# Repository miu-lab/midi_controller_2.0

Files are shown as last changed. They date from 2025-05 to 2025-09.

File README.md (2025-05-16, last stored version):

# MIDI Controller

MIDI Controller est un projet de contrôleur MIDI pour la plateforme Teensy, utilisant PlatformIO pour la gestion du projet et la compilation. Il offre une architecture modulaire et extensible pour le développement d'applications de contrôle MIDI.

## Vue d'ensemble

Ce projet implémente un contrôleur MIDI complet avec:
- Support pour encodeurs rotatifs, boutons et autres contrôles
- Affichage OLED pour l'interface utilisateur
- Communication MIDI via USB
- Gestion de profils et configurations personnalisables

## Architecture

Le projet est organisé selon une architecture hexagonale (aussi appelée architecture en oignon) avec injection de dépendances:

### Couches Principales

- **Core** : Contient la logique métier principale, indépendante de l'implémentation
  - **Domain** : Définitions des entités et interfaces principales
  - **Use Cases** : Implémentation des cas d'utilisation
  - **Ports** : Interfaces pour les adaptateurs
  - **Interfaces** : Contrats abstraits pour les sous-systèmes

- **Adapters** : Implémentations concrètes des interfaces
  - **Primary** : Adaptateurs d'entrée (UI, contrôles)
  - **Secondary** : Adaptateurs de sortie (MIDI, stockage)

- **App** : Point d'entrée de l'application et orchestration
  - **Subsystems** : Sous-systèmes modulaires encapsulant des fonctionnalités complètes
  - **DI** : Système d'injection de dépendances moderne

### Sous-systèmes

L'application est divisée en sous-systèmes indépendants, chacun implémentant une interface abstraite:

- **ConfigurationSubsystem** (`IConfiguration`): Gestion des paramètres et préférences
- **InputSubsystem** (`IInputSystem`): Traitement des entrées utilisateur
- **MidiSubsystem** (`IMidiSystem`): Communication MIDI et mapping
- **UISubsystem** (`IUISystem`): Interface utilisateur et affichage

## Fonctionnalités Principales

- **Mapping MIDI flexible**: Assignez facilement des contrôles à différents messages MIDI
- **Interface utilisateur intuitive**: Navigation par menus sur écran OLED
- **Profils multiples**: Sauvegardez et chargez différentes configurations
- **Mode d'apprentissage**: Apprenez facilement de nouveaux mappings MIDI
- **Modularité**: Ajoutez de nouvelles fonctionnalités sans modifier le code existant

## Compilation et Déploiement

### Prérequis
- PlatformIO
- Teensy Loader
- Librairies Arduino requises (voir platformio.ini)

### Compilation
```bash
pio run
```

### Upload vers le Teensy
```bash
pio run -t upload
```

### Moniteur Série
```bash
pio device monitor
```

## Tests

Le projet comprend une infrastructure de tests unitaires et d'intégration basée sur Unity:

```bash
pio test
```

Les tests couvrent les composants individuels ainsi que l'intégration des sous-systèmes.

## Contribution

Les contributions sont les bienvenues! Veuillez consulter [CONTRIBUTING.md](CONTRIBUTING.md) pour les lignes directrices sur la façon de contribuer au projet.

## Licence

Ce projet est sous licence MIT. Voir le fichier LICENSE pour plus de détails.

## Contact

Pour toute question ou suggestion, veuillez ouvrir une issue sur le dépôt GitHub du projet.

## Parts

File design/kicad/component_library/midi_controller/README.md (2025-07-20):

# MIDI Controller - Bibliothèque de Composants Unifiée

Cette bibliothèque contient tous les composants nécessaires pour le projet de contrôleur MIDI, organisés de manière cohérente et professionnelle.

## Structure de la Bibliothèque

```
midi_controller/
├── midi_controller.kicad_sym     # Symboles schématiques unifiés
├── midi_controller.pretty/       # Footprints PCB
├── 3d_models/                   # Modèles 3D
├── datasheets/                  # Documentation technique
└── README.md                    # Ce fichier
```

## Composants Disponibles

### 🎛️ Microcontrôleurs
- **MIDI_Teensy4.1** - Teensy 4.1 (ARM Cortex-M7 600MHz)
  - Footprint: `Teensy41.kicad_mod`
  - Modèle 3D: `Teensy_4.1_Assembly.STEP`
  - Datasheet: https://www.pjrc.com/store/teensy41.html

### 🖥️ Affichages
- **MIDI_Display_MSP2807** - Écran TFT 2.8" ILI9341 320x240 avec touch
  - Footprint: `MSP2807_ILI9341_Display`
  - Interface: SPI (display) + SPI (touch)
  - Alimentation: 3.3V/5V
  - Résolution: 320×240 pixels
  - Contrôleur: ILI9341
  - Touch controller intégré
  - Utilisé avec LVGL 9.3.0

### 🔄 Encodeurs
- **MIDI_Encoder_PEC11R** - Encodeur mécanique Bourns PEC11R
  - Footprint: `PEC11R4220FS0024.kicad_mod`
  - Modèle 3D: `PEC11R-4020F-S0024.stp`
  - Résolution: 24 impulsions/tour
  - Avec bouton poussoir intégré

- **MIDI_Encoder_E38S6G5_Optical** - Encodeur optique haute précision
  - Footprint: `E38S6G5_Optical_Encoder`
  - Modèle: E38S6G5-600B-G24N
  - Résolution: 600 pulses/révolution
  - Diamètre: Ø38mm
  - Sortie: Open Collector NPN (phases A, B)
  - Alimentation: 5-24V
  - Montage: 3 vis M4 sur cercle Ø30mm
  - Type: Optique incrémental haute précision

### 🔘 Boutons
- **MIDI_Button_Tactile** - Bouton tactile momentané
  - Footprint: `Button_Tactile_6x6mm` (à créer)
  - Type: Momentané NO (Normalement Ouvert)

## Convention de Nommage

### Symboles
- Préfixe: `MIDI_`
- Format: `MIDI_[Catégorie]_[Modèle]`
- Exemple: `MIDI_Encoder_PEC11R`

### Footprints
- Nom descriptif sans préfixe
- Format: `[Modèle]_[Spécification]`
- Exemple: `PEC11R4220FS0024`

### Modèles 3D
- Nom du modèle + extension
- Formats supportés: `.step`, `.stp`, `.wrl`

## Utilisation dans KiCad

### 1. Intégration Automatique
La bibliothèque est automatiquement intégrée via `sym-lib-table` :
```
(lib (name "midi_controller")(type "KiCad")(uri "${KIPRJMOD}/component_library/midi_controller/midi_controller.kicad_sym")(options "")(descr "Unified MIDI Controller Component Library"))
```

### 2. Accès aux Composants
1. Ouvrir l'éditeur de schématique
2. Placer un symbole (touche 'A')
3. Chercher dans la bibliothèque `midi_controller`
4. Sélectionner le composant désiré

### 3. Footprints
Les footprints sont automatiquement associés aux symboles via la propriété `Footprint` :
- Format: `midi_controller:[NomFootprint]`
- Exemple: `midi_controller:Teensy41`

## Gestion des Versions

### Structure de Version
- **v1.0** : Version initiale avec composants de base
- **v1.x** : Ajouts de composants, corrections mineures
- **v2.x** : Modifications majeures de structure

### Changelog
- **v1.0** (2025-01-20) : Création de la bibliothèque unifiée
  - Migration depuis bibliothèques séparées
  - Standardisation des noms et propriétés
  - Documentation complète

## Ajout de Nouveaux Composants

### Processus
1. **Créer le symbole** dans `midi_controller.kicad_sym`
2. **Ajouter le footprint** dans `midi_controller.pretty/`
3. **Inclure modèle 3D** dans `3d_models/` si disponible
4. **Ajouter documentation** dans `datasheets/` si nécessaire
5. **Mettre à jour** ce README.md

### Standards Requis
- **Documentation Doxygen** pour toutes les propriétés
- **Mots-clés** appropriés (`ki_keywords`)
- **Footprint associé** (`Footprint` property)
- **Datasheet URL** quand disponible
- **Description claire** du composant

## Maintenance

### Vérifications Régulières
- [ ] Cohérence des noms de symboles/footprints
- [ ] Validité des liens de datasheets
- [ ] Présence des modèles 3D
- [ ] Conformité aux standards KiCad

### Backup
- La bibliothèque est versionnée avec le projet
- Sauvegardes automatiques dans `midi_controller-backups/`

## Support

Pour toute question ou amélioration :
1. Créer une issue dans le projet
2. Proposer des modifications via pull request
3. Consulter la documentation KiCad officielle

---
*Bibliothèque maintenue pour le projet MIDI Controller v2.0*

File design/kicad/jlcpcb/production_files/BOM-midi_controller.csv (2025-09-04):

Comment | Designator | Footprint | LCSC | Quantity
~ | FB1,FB2,FB3,FB4 | FB_0805 | C1015 | 4
100nF | C1,C10,C11,C12,C13,C14,C15,C16,C17,C18,C19,C2,C20,C21,C3,C38,C39,C40,C41,C42,C43,C44,C45,C5,C6,C7,C8,C9 | C_0603 | C14663 | 28
100pF | C22 | C_0603 | C14858 | 1
100uF | C23 | C_1206 | C15008 | 1
6N137 | U2 | SOP-8_6.605x9.655mm_P2.54mm | C15825 | 1
10uF | C31,C35,C4 | C_0805 | C15850 | 3
1nF | C24,C37 | C_0603 | C1588 | 2
47uF | C27,C33 | C_0805 | C16780 | 2
1k | R10 | R_0805_2012Metric | C17513 | 1
220 | R11,R12,R9 | R_0805_2012Metric | C17557 | 3
100 | R2,R3,R4,R5 | R_0603_1608Metric | C22775 | 4
220 | R13 | R_0603_1608Metric | C22962 | 1
33Ω | R1,R6,R7,R8 | R_0603 | C23140 | 4
100nF | C25,C26,C28,C30,C32,C34,C36 | C_0805 | C28233 | 7
Conn_01x02_Socket | J10,J11,J4,J5,J7,J9 | JST_XH_B2B-XH-A_1x02_P2.50mm_Vertical_JLC_Constraints | C2908600 | 6
Conn_01x05 | J8 | JST_XH_B5B-XH-A_1x05_P2.50mm_Vertical | C2908603 | 1
Conn_01x24_Socket | J3,J6 | PinSocket_1x24_P2.54mm_Vertical | C41376163 | 2
CD74HC4067M | U1 | SOIC-24W_7.5x15.4mm_P1.27mm | C496123 | 1
74HC14D,653 | U3 | SOIC-14_L8.7-W3.9-P1.27-LS6.0-BL | C5605 | 1
10nF | C29 | C_0603 | C57112 | 1
PESD5V0L1BA,115 | D1,D10,D11,D12,D13,D14,D15,D16,D17,D18,D19,D2,D20,D21,D22,D23,D24,D25,D26,D27,D28,D29,D3,D30,D31,D32,D33,D34,D35,D36,D37,D4,D5,D6,D7,D8,D9 | SOD2512X110N | C85380 | 37
Fuse | F1 | Fuse_0805_2012Metric | C883101 | 1

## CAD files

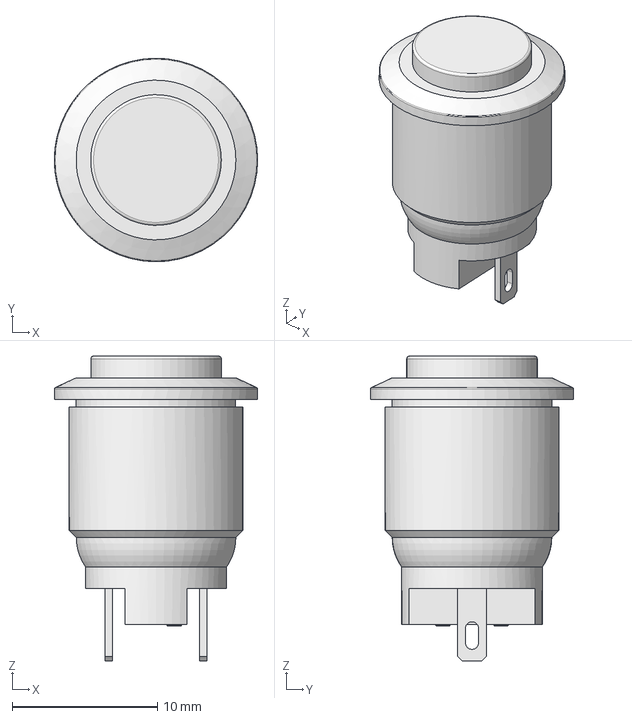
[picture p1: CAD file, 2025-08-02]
design/kicad/component_library/Buttons/PV0H240/PUSH_BUTTON_PV0H240xx.step
14.0 x 14.0 x 21.0 mm

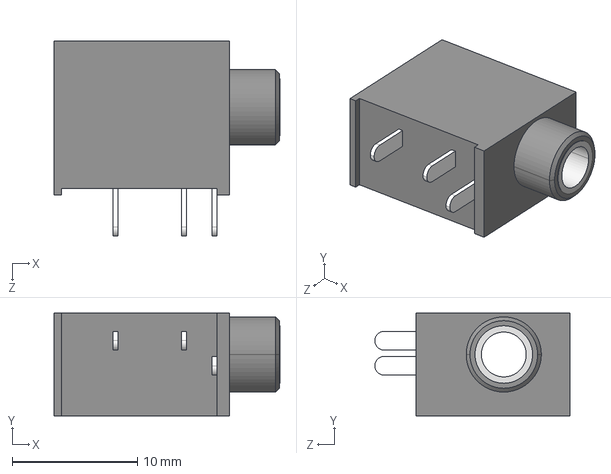
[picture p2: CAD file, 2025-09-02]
design/kicad/component_library/Connector/Audio/Same_Sky_SJ1-3533NG.step
18.1 x 8.20 x 15.6 mm

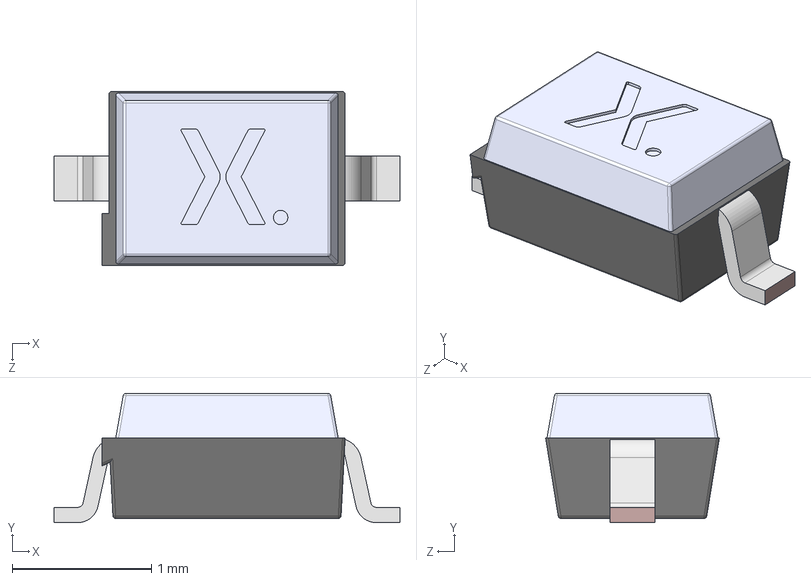
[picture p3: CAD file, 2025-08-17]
design/kicad/component_library/Diode/PESD5V0L1BA,115/3D/PESD5V0L1BA,115.stp
2.49 x 0.93 x 1.25 mm
SOD323 Lower body
SOD323 Lead x 2
SOD323 Upper body

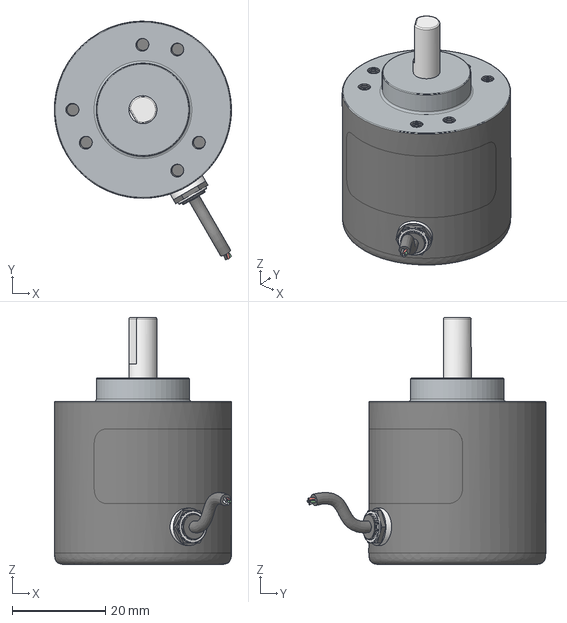
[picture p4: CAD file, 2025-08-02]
design/kicad/component_library/Encoders/Optical_E38S6G5/OPTICAL_ENCODER.step
38.0 x 51.2 x 53.0 mm

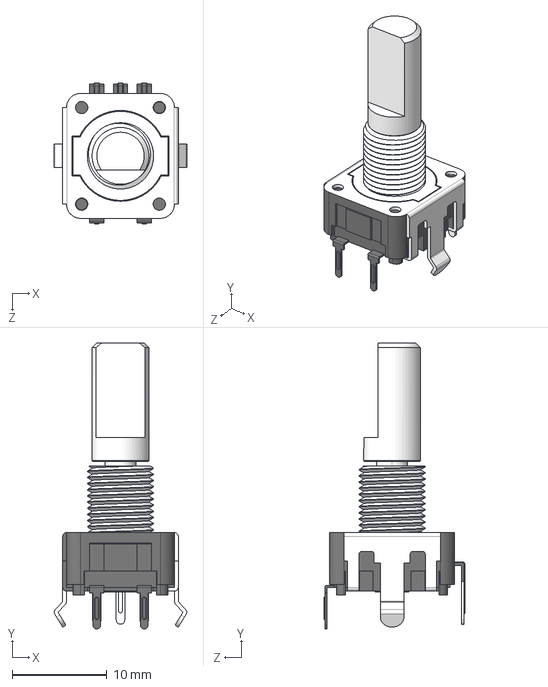
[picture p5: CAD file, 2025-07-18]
design/kicad/component_library/midi_controller/3d_models/PEC11R-4020F-S0024.stp
14.0 x 30.2 x 14.9 mm

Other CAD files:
design/fab/BODY_AND_SUPPORTS.dxf
design/fab/PANEL_FRONT_A4.dxf
design/kicad/component_library/Microcontrollers/Teensy/Teensy 4.1.x_b

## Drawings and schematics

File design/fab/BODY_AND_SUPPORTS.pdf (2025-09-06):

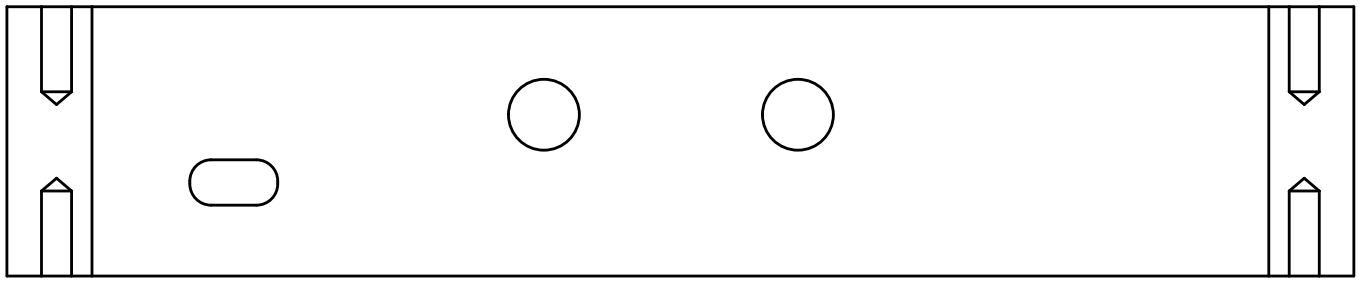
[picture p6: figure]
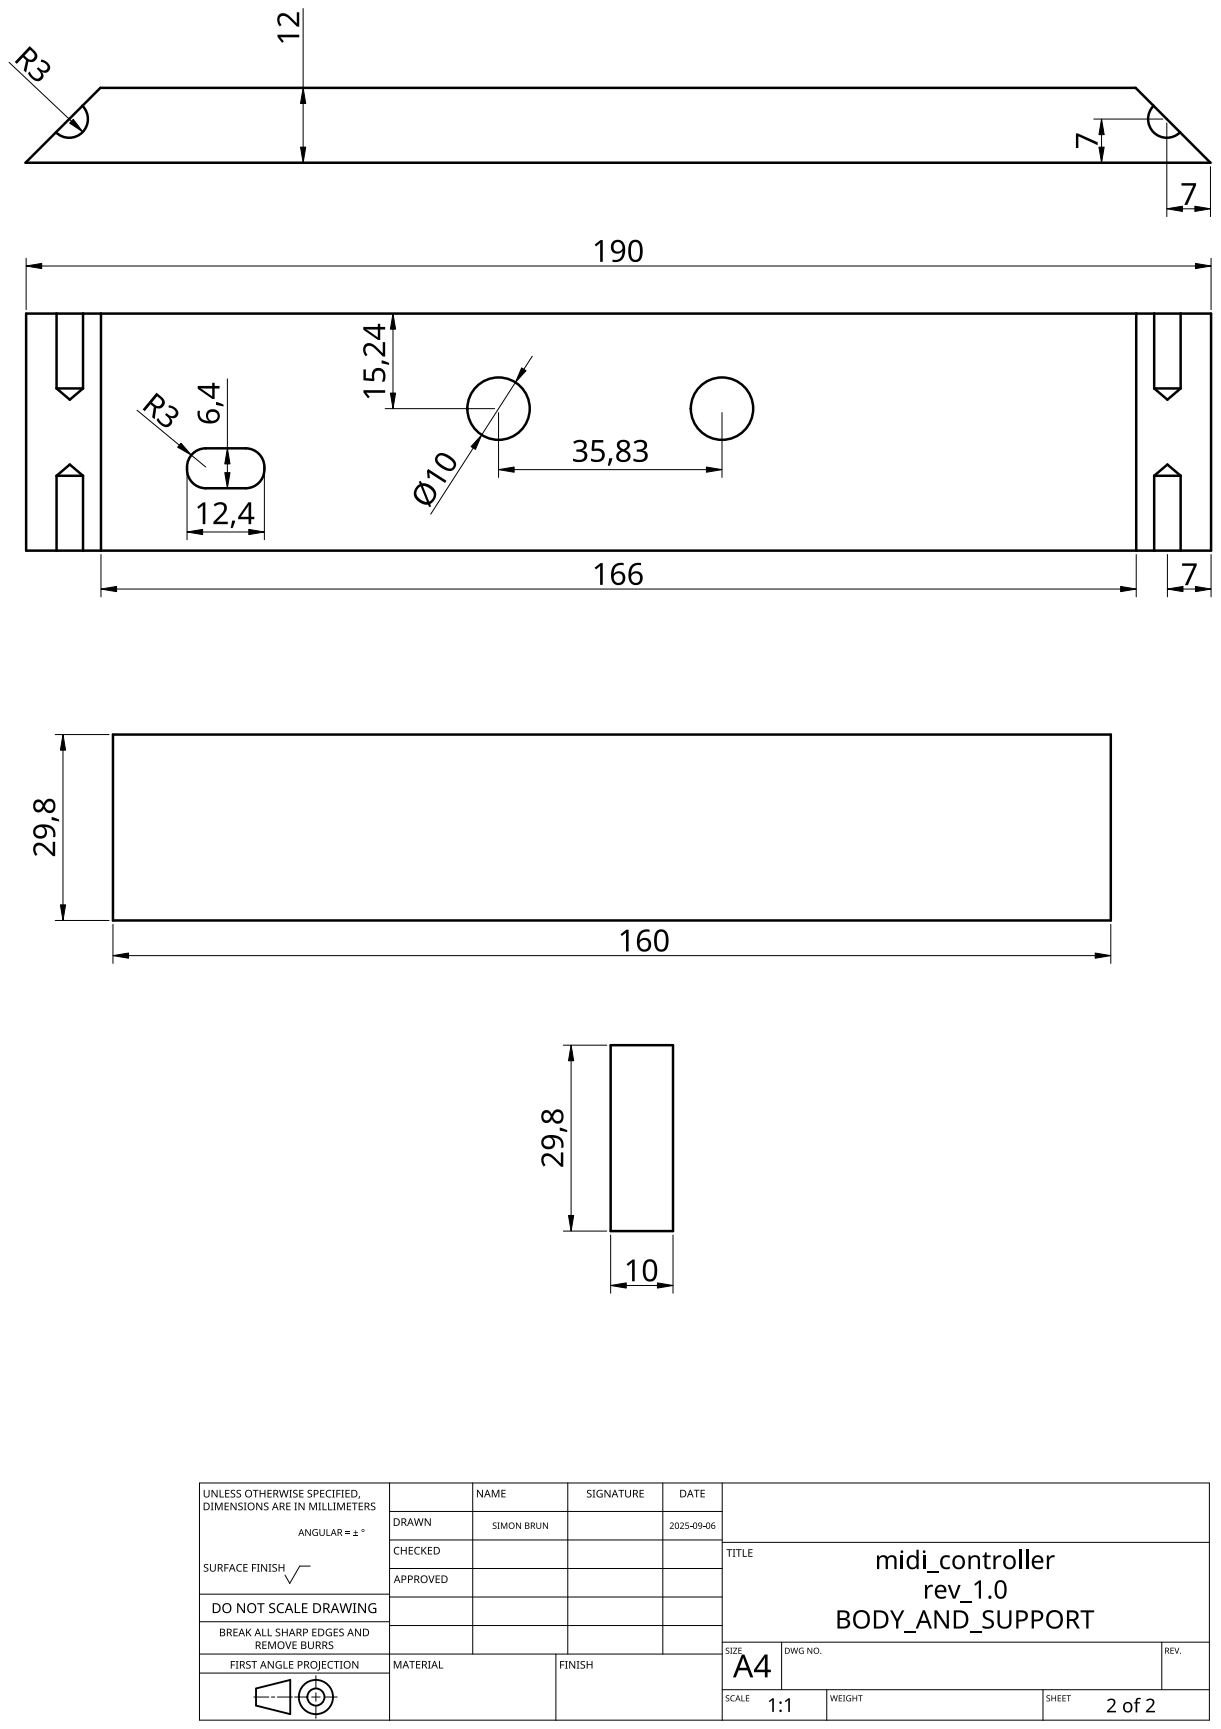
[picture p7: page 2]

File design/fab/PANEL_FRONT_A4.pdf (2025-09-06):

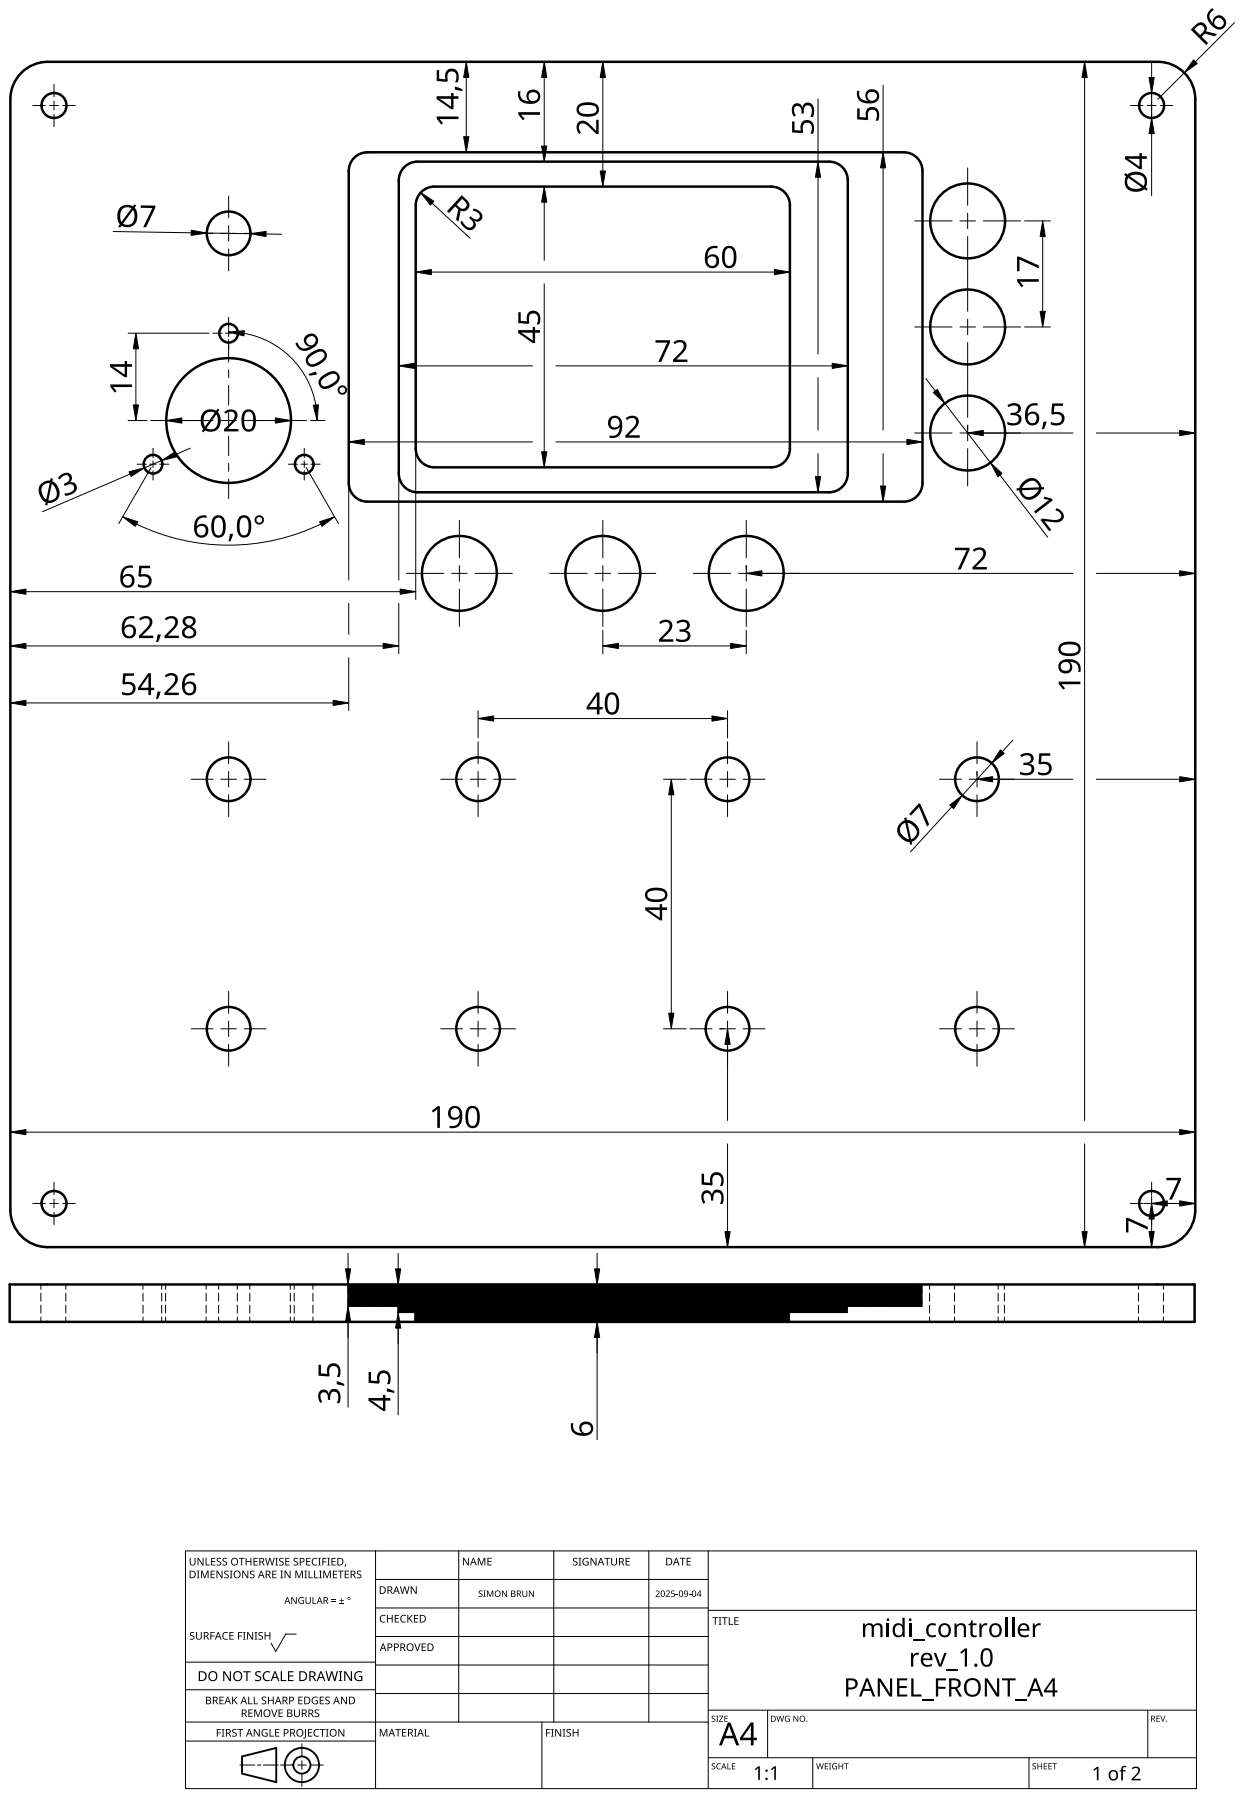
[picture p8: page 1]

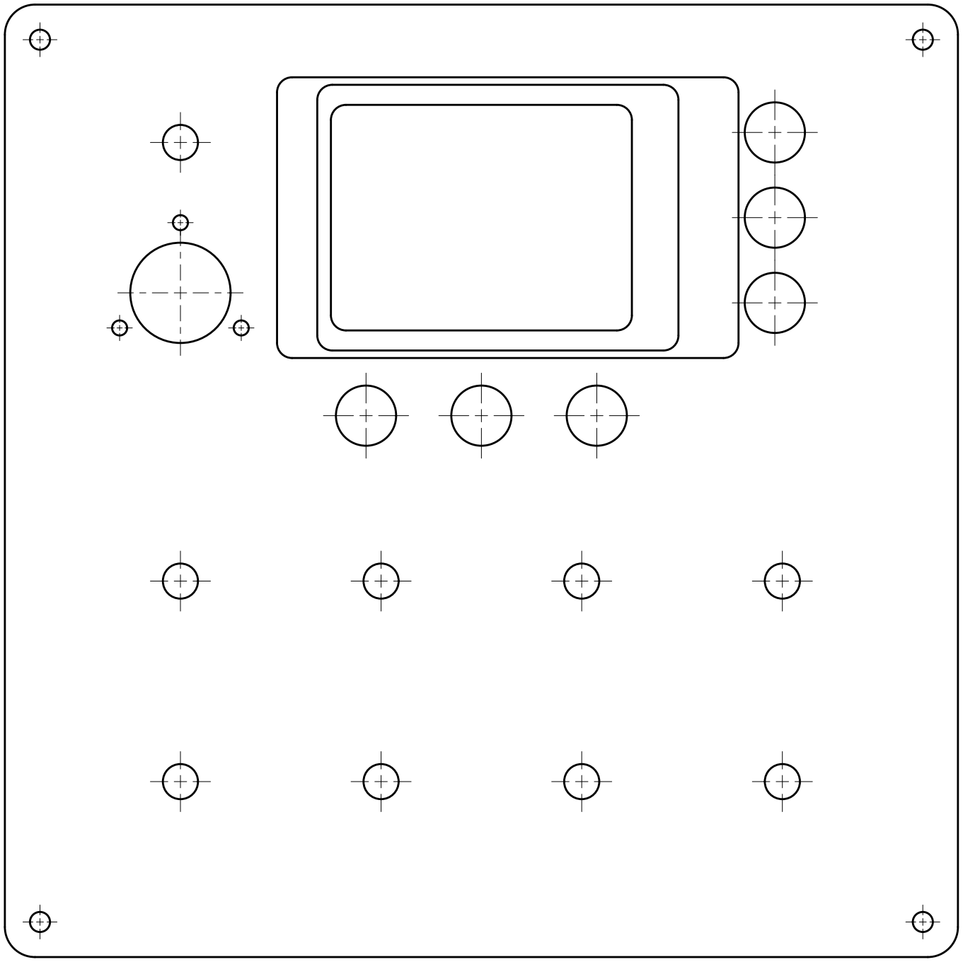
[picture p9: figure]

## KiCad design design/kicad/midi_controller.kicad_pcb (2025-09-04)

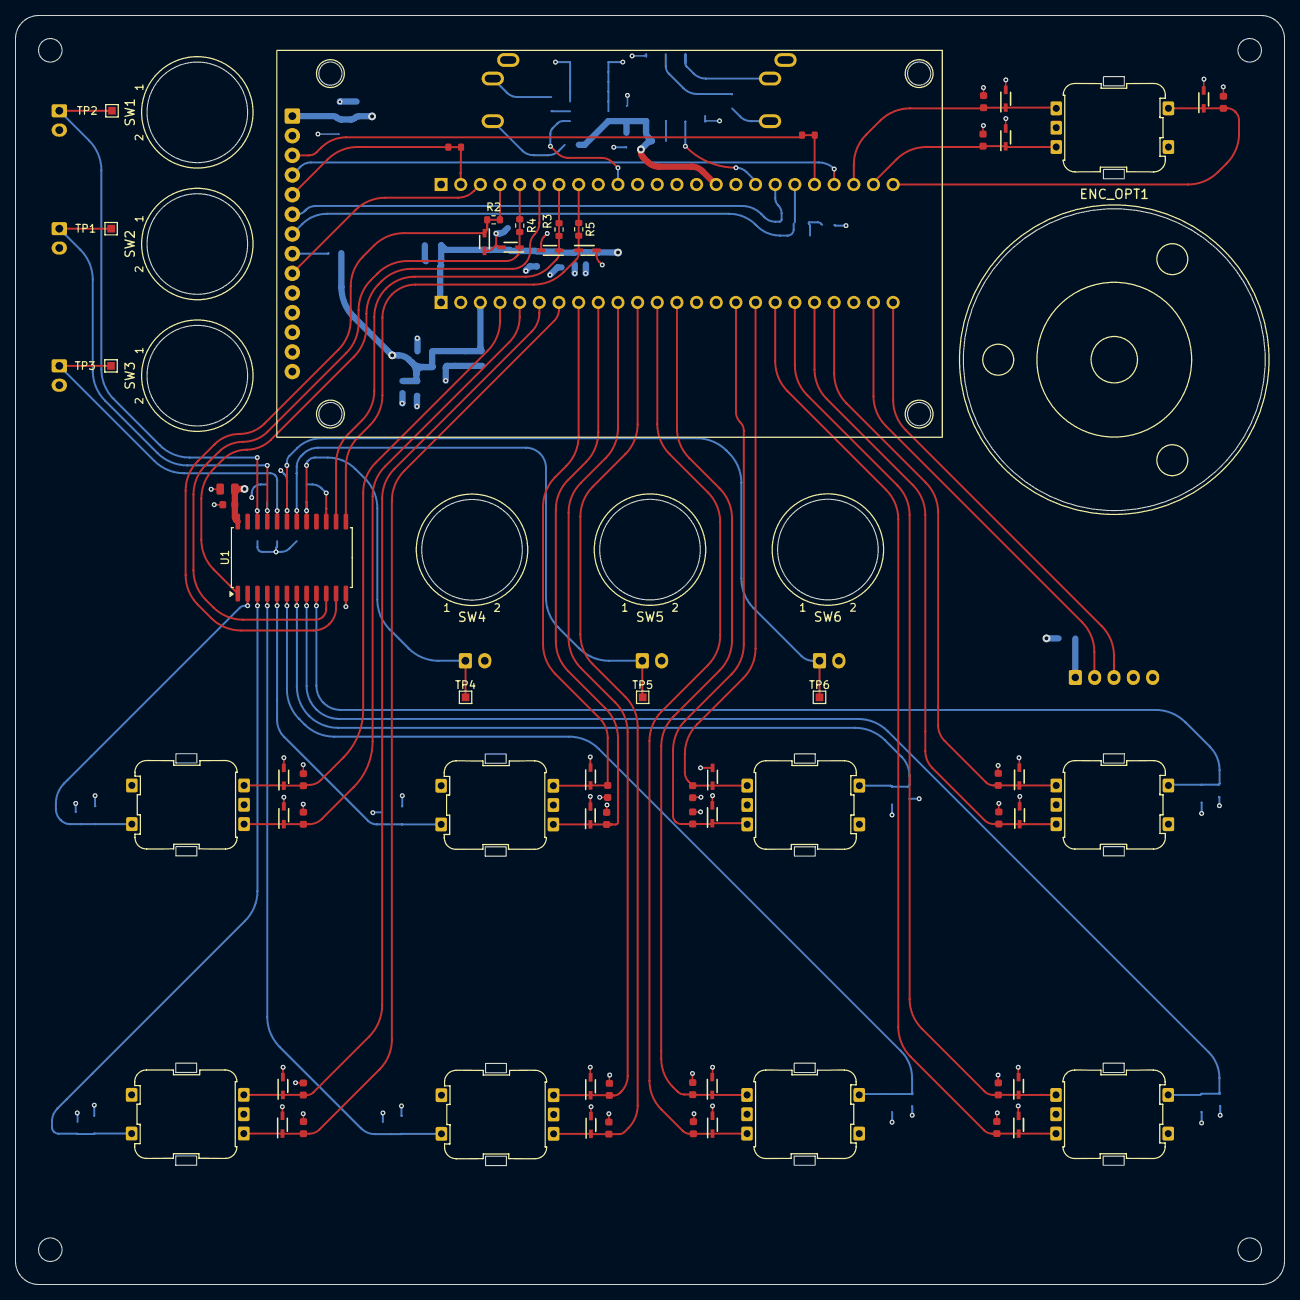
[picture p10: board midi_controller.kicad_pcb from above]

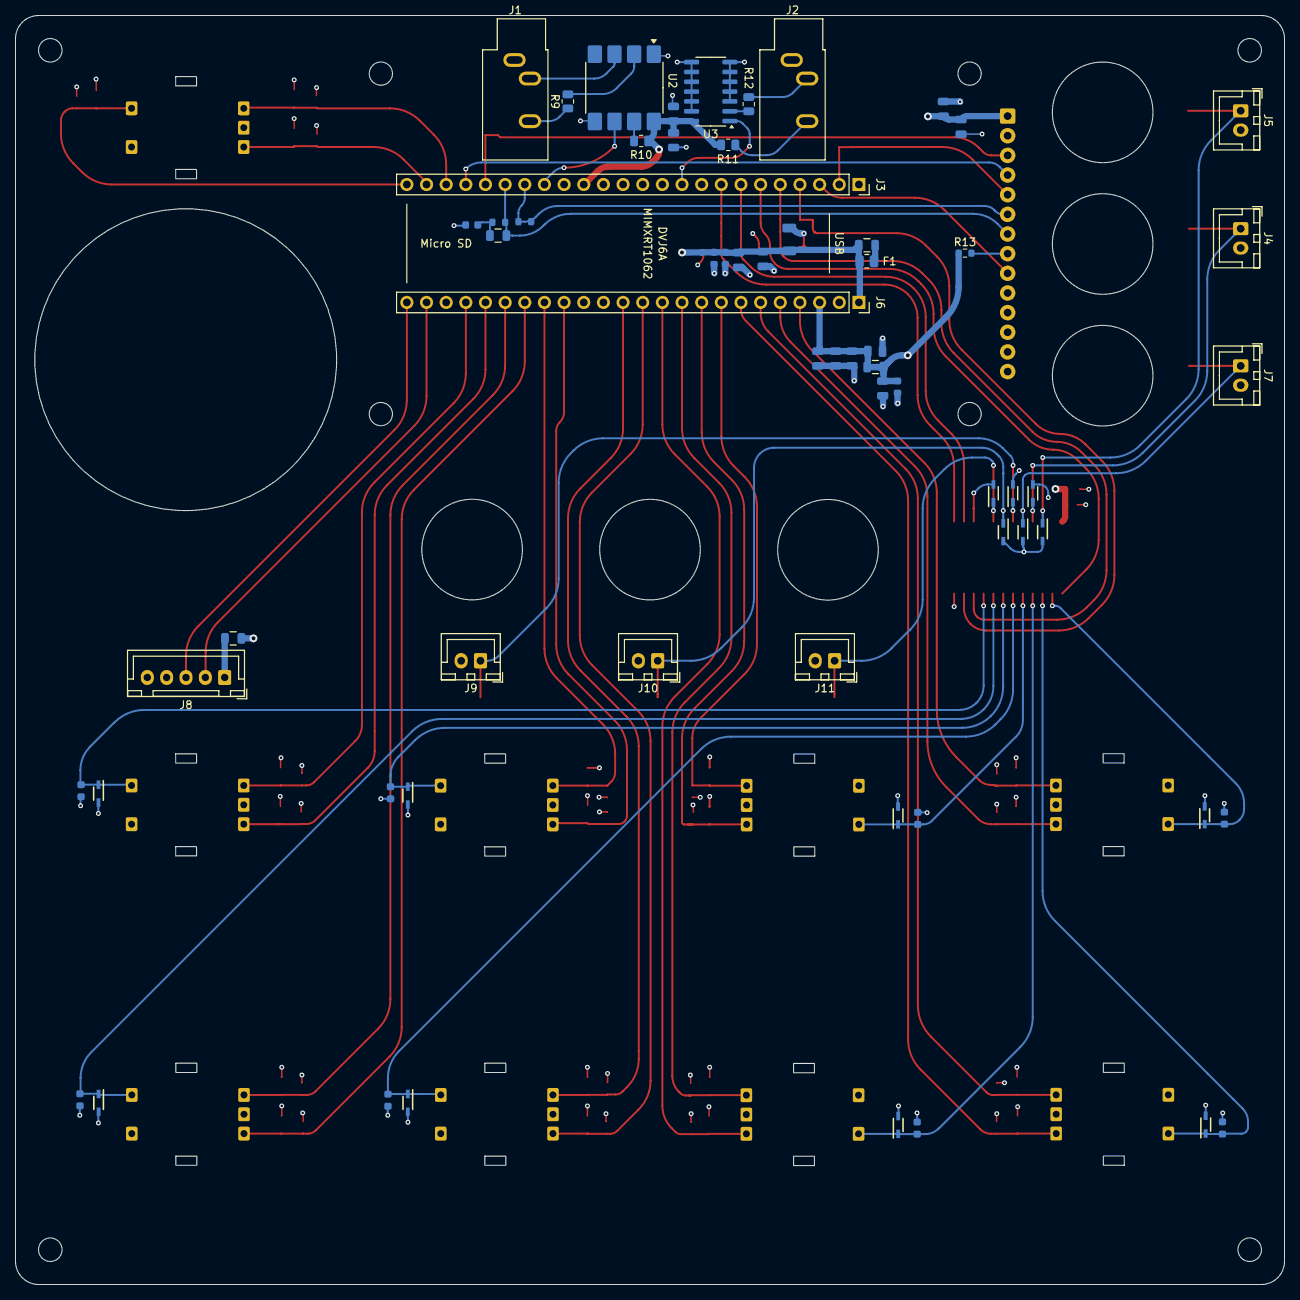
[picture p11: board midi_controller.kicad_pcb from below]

Board: 4 copper layers, 164.0 x 164.0 mm, 138 parts (64 on the bottom side), 63 nets.

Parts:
C1, C2, C3, C5, C6, C7, C8, C9, C10, C11, C12, C13, C14, C15, C16, C17, C18, C19, C20, C21, C38, C39, C40, C41, C42, C43, C44, C45: 100nF; C_0603
C4, C31, C35: 10uF; C_0805
C22: 100pF; C_0603
C23: 100uF; C_1206
C24, C37: 1nF; C_0603
C25, C26, C28, C30, C32, C34, C36: 100nF; C_0805
C27, C33: 47uF; C_0805
C29: 10nF; C_0603
D1, D2, D3, D4, D5, D6, D7, D8, D9, D10, D11, D12, D13, D14, D15, D16, D17, D18, D19, D20, D21, D22, D23, D24, D25, D26, D27, D28, D29, D30, D31, D32, D33, D34, D35, D36, D37: PESD5V0L1BA,115; SOD2512X110N
DISP1: MIDI_Display_MSP2807; MSP2807_ILI9341_Display
ENC_MECH1, ENC_MECH2, ENC_MECH3, ENC_MECH4, ENC_MECH5, ENC_MECH6, ENC_MECH7, ENC_MECH8, ENC_MECH9: MIDI_Encoder_PEC11R; PEC11R4220FS0024
ENC_OPT1: MIDI_Encoder_E38S6G5_Optical; E38S6G5_Optical_Encoder
F1: Fuse; Fuse_0805_2012Metric
FB1, FB2, FB3, FB4: FB_0805
J1: MIDI In; Jack_3.5mm_CUI_SJ1-3533NG_Horizontal
J2: MIDI Out; Jack_3.5mm_CUI_SJ1-3533NG_Horizontal
J3, J6: Conn_01x24_Socket; PinSocket_1x24_P2.54mm_Vertical
J4, J5, J7, J9, J10, J11: Conn_01x02_Socket; JST_XH_B2B-XH-A_1x02_P2.50mm_Vertical_JLC_Constraints
J8: Conn_01x05; JST_XH_B5B-XH-A_1x05_P2.50mm_Vertical
MCU1: MIDI_Teensy4.1; Teensy41_Mechanical
R1, R6, R7, R8: 33Ω; R_0603
R2, R3, R4, R5: 100; R_0603_1608Metric
R9, R11, R12: 220; R_0805_2012Metric
R10: 1k; R_0805_2012Metric
R13: 220; R_0603_1608Metric
SW1, SW2, SW3, SW4, SW5, SW6: PV0H24011_Pushbutton
TP1, TP2, TP3, TP4, TP5, TP6: TestPoint; TestPoint_Pad_1.0x1.0mm
U1: CD74HC4067M; SOIC-24W_7.5x15.4mm_P1.27mm
U2: 6N137; SOP-8_6.605x9.655mm_P2.54mm
U3: 74HC14D,653; SOIC-14_L8.7-W3.9-P1.27-LS6.0-BL

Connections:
+3V3_A: C4.1, C5.1, C32.1, C33.1, C34.1, C35.1, C36.1, C37.1, FB3.1, FB3.2, J6.3, R13.1, U1.24 (VCC)
+3V3_B: C26.1, C28.2, J3.15, R10.2, R11.1, U2.8 (VCC), U3.14 (VCC)
+5V: C23.1, C24.1, C25.1, C27.1, C29.1, C30.2, C31.1, DISP1.1 (VCC), F1.1, FB2.1, FB4.2, J6.1
/Buttons_Momentary/BUTTON_PUSH_MOM_01: D26.1 (K1), J5.1, TP2.1, U1.22 (I9)
/Buttons_Momentary/BUTTON_PUSH_MOM_02: D29.1 (K1), J4.1, TP1.1, U1.21 (I10)
/Buttons_Momentary/BUTTON_PUSH_MOM_03: D28.1 (K1), J7.1, TP3.1, U1.20 (I11)
/Buttons_Momentary/BUTTON_PUSH_MOM_04: D27.1 (K1), J9.1, TP6.1, U1.19 (I12)
/Buttons_Momentary/BUTTON_PUSH_MOM_05: D24.1 (K1), J10.1, TP5.1, U1.18 (I13)
/Buttons_Momentary/BUTTON_PUSH_MOM_06: D25.1 (K1), J11.1, TP4.1, U1.17 (I14)
/COM: J3.6, U1.1 (COM)
/CS: DISP1.3 (CS), J3.20, R6.1, R6.2
/DC: DISP1.5 (DC), J3.2, R1.1, R1.2
/LED: DISP1.8 (LED), R13.2
/MIDI_Encoder_Matrix_2x4_with_push_buttons/1x1.QUAD_A: C7.2, D9.1 (K1), ENC_MECH2.A, J6.5
/MIDI_Encoder_Matrix_2x4_with_push_buttons/1x1.QUAD_B: C6.2, D8.1 (K1), ENC_MECH2.B, J6.4
/MIDI_Encoder_Matrix_2x4_with_push_buttons/1x1_SW_A: C41.2, D33.1 (K1), ENC_MECH2.1 (SW1), U1.2 (I7)
/MIDI_Encoder_Matrix_2x4_with_push_buttons/1x2.QUAD_A: C8.2, D11.1 (K1), ENC_MECH3.A, J6.9
/MIDI_Encoder_Matrix_2x4_with_push_buttons/1x2.QUAD_B: C9.2, D10.1 (K1), ENC_MECH3.B, J6.8
/MIDI_Encoder_Matrix_2x4_with_push_buttons/1x2_SW_A: C40.2, D32.1 (K1), ENC_MECH3.1 (SW1), U1.5 (I4)
/MIDI_Encoder_Matrix_2x4_with_push_buttons/1x3.QUAD_A: C10.2, D12.1 (K1), ENC_MECH4.A, J6.17
/MIDI_Encoder_Matrix_2x4_with_push_buttons/1x3.QUAD_B: C11.2, D13.1 (K1), ENC_MECH4.B, J6.16
/MIDI_Encoder_Matrix_2x4_with_push_buttons/1x3_SW_A: C39.2, D31.1 (K1), ENC_MECH4.1 (SW1), U1.7 (I2)
/MIDI_Encoder_Matrix_2x4_with_push_buttons/1x4.QUAD_A: C12.2, D14.1 (K1), ENC_MECH5.A, J6.21
/MIDI_Encoder_Matrix_2x4_with_push_buttons/1x4.QUAD_B: C13.2, D15.1 (K1), ENC_MECH5.B, J6.20
/MIDI_Encoder_Matrix_2x4_with_push_buttons/1x4_SW_A: C38.2, D30.1 (K1), ENC_MECH5.1 (SW1), U1.9 (I0)
/MIDI_Encoder_Matrix_2x4_with_push_buttons/2x1.QUAD_A: C14.2, D17.1 (K1), ENC_MECH6.A, J6.7
/MIDI_Encoder_Matrix_2x4_with_push_buttons/2x1.QUAD_B: C15.2, D16.1 (K1), ENC_MECH6.B, J6.6
/MIDI_Encoder_Matrix_2x4_with_push_buttons/2x1_SW_A: C45.2, D37.1 (K1), ENC_MECH6.1 (SW1), U1.3 (I6)
/MIDI_Encoder_Matrix_2x4_with_push_buttons/2x2.QUAD_A: C16.2, D18.1 (K1), ENC_MECH7.A, J6.11
/MIDI_Encoder_Matrix_2x4_with_push_buttons/2x2.QUAD_B: C17.2, D19.1 (K1), ENC_MECH7.B, J6.10
/MIDI_Encoder_Matrix_2x4_with_push_buttons/2x2_SW_A: C44.2, D36.1 (K1), ENC_MECH7.1 (SW1), U1.4 (I5)
/MIDI_Encoder_Matrix_2x4_with_push_buttons/2x3.QUAD_A: C19.2, D20.1 (K1), ENC_MECH8.A, J6.13
/MIDI_Encoder_Matrix_2x4_with_push_buttons/2x3.QUAD_B: C18.2, D21.1 (K1), ENC_MECH8.B, J6.12
/MIDI_Encoder_Matrix_2x4_with_push_buttons/2x3_SW_A: C43.2, D35.1 (K1), ENC_MECH8.1 (SW1), U1.6 (I3)
/MIDI_Encoder_Matrix_2x4_with_push_buttons/2x4.QUAD_A: C20.2, D22.1 (K1), ENC_MECH9.A, J6.19
/MIDI_Encoder_Matrix_2x4_with_push_buttons/2x4.QUAD_B: C21.2, D23.1 (K1), ENC_MECH9.B, J6.18
/MIDI_Encoder_Matrix_2x4_with_push_buttons/2x4_SW_A: C42.2, D34.1 (K1), ENC_MECH9.1 (SW1), U1.8 (I1)
/MISO: DISP1.9 (SDO/MISO), J3.3
/MOSI: DISP1.6 (SDI/MOSI), J3.18, R8.1, R8.2
/NAV.QUAD_A: C1.2, D1.1 (K1), ENC_MECH1.A, J3.22
/NAV.QUAD_B: C2.2, D7.1 (K1), ENC_MECH1.B, J3.23
/NAV.SW: C3.2, D2.1 (K1), ENC_MECH1.1 (SW1), J3.24
/OPT.QUAD_A: J6.23, J8.2
/OPT.QUAD_B: J6.24, J8.3
/RST: DISP1.4 (RST), J3.21
/RX6: J3.17, U2.6 (VO)
/S0: D5.1 (K1), J3.5, R4.1, R4.2, U1.10 (S0)
/S1: D3.1 (K1), J3.4, R2.1, R2.2, U1.11 (S1)
/S2: D6.1 (K1), J3.7, R3.1, R3.2, U1.14 (S2)
/S3: D4.1 (K1), J3.8, R5.1, R5.2, U1.13 (S3)
/SCK: DISP1.7 (SCK), FB1.1, J3.19, R7.2
/TX2: J3.10, U3.1 (1A)
GND: C1.1, C2.1, C3.1, C4.2, C5.2, C6.1, C7.1, C8.1, C9.1, C10.1, C11.1, C12.1, C13.1, C14.1, C15.1, C16.1, C17.1, C18.1, C19.1, C20.1, C21.1, C22.2, C23.2, C24.2, C25.2, C26.2, C27.2, C28.1, C29.2, C30.1, C31.2, C32.2, C33.2, C34.2, C35.2, C36.2, C37.2, C38.1, C39.1, C40.1, C41.1, C42.1, C43.1, C44.1, C45.1, D1.2 (K2), D2.2 (K2), D3.2 (K2), D4.2 (K2), D5.2 (K2), D6.2 (K2), D7.2 (K2), D8.2 (K2), D9.2 (K2), D10.2 (K2), D11.2 (K2), D12.2 (K2), D13.2 (K2), D14.2 (K2), D15.2 (K2), D16.2 (K2), D17.2 (K2), D18.2 (K2), D19.2 (K2), D20.2 (K2), D21.2 (K2), D22.2 (K2), D23.2 (K2), D24.2 (K2), D25.2 (K2), D26.2 (K2), D27.2 (K2), D28.2 (K2), D29.2 (K2), D30.2 (K2), D31.2 (K2), D32.2 (K2), D33.2 (K2), D34.2 (K2), D35.2 (K2), D36.2 (K2), D37.2 (K2), DISP1.2 (GND), ENC_MECH1.2 (GND), ENC_MECH1.C (GND), ENC_MECH2.2 (GND), ENC_MECH2.C (GND), ENC_MECH3.2 (GND), ENC_MECH3.C (GND), ENC_MECH4.2 (GND), ENC_MECH4.C (GND), ENC_MECH5.2 (GND), ENC_MECH5.C (GND), ENC_MECH6.2 (GND), ENC_MECH6.C (GND), ENC_MECH7.2 (GND), ENC_MECH7.C (GND), ENC_MECH8.2 (GND), ENC_MECH8.C (GND), ENC_MECH9.2 (GND), ENC_MECH9.C (GND), J1.S, J2.S, J3.1, J4.2, J5.2, J6.2, J6.15, J7.2, J8.4, J8.5, J9.2, J10.2, J11.2, U1.12 (GND), U1.15 (~E), U2.1 (NC), U2.5 (GND), U3.3 (2A), U3.4 (2Y), U3.5 (3A), U3.6 (3Y), U3.7 (GND), U3.8 (4Y), U3.9 (4A), U3.10 (5Y), U3.11 (5A), U3.12 (6Y), U3.13 (6A)
unnamed: C22.1, FB1.2, R7.1
unnamed: F1.2, FB2.2
unnamed: J1.R, R9.1
unnamed: J2.R, R11.2
unnamed: J2.T, R12.2
unnamed: FB4.1, J8.1
unnamed: R9.2, U2.2 (A)
unnamed: J1.T, U2.3 (C)
unnamed: R10.1, U2.7 (EN)
unnamed: R12.1, U3.2 (1Y)

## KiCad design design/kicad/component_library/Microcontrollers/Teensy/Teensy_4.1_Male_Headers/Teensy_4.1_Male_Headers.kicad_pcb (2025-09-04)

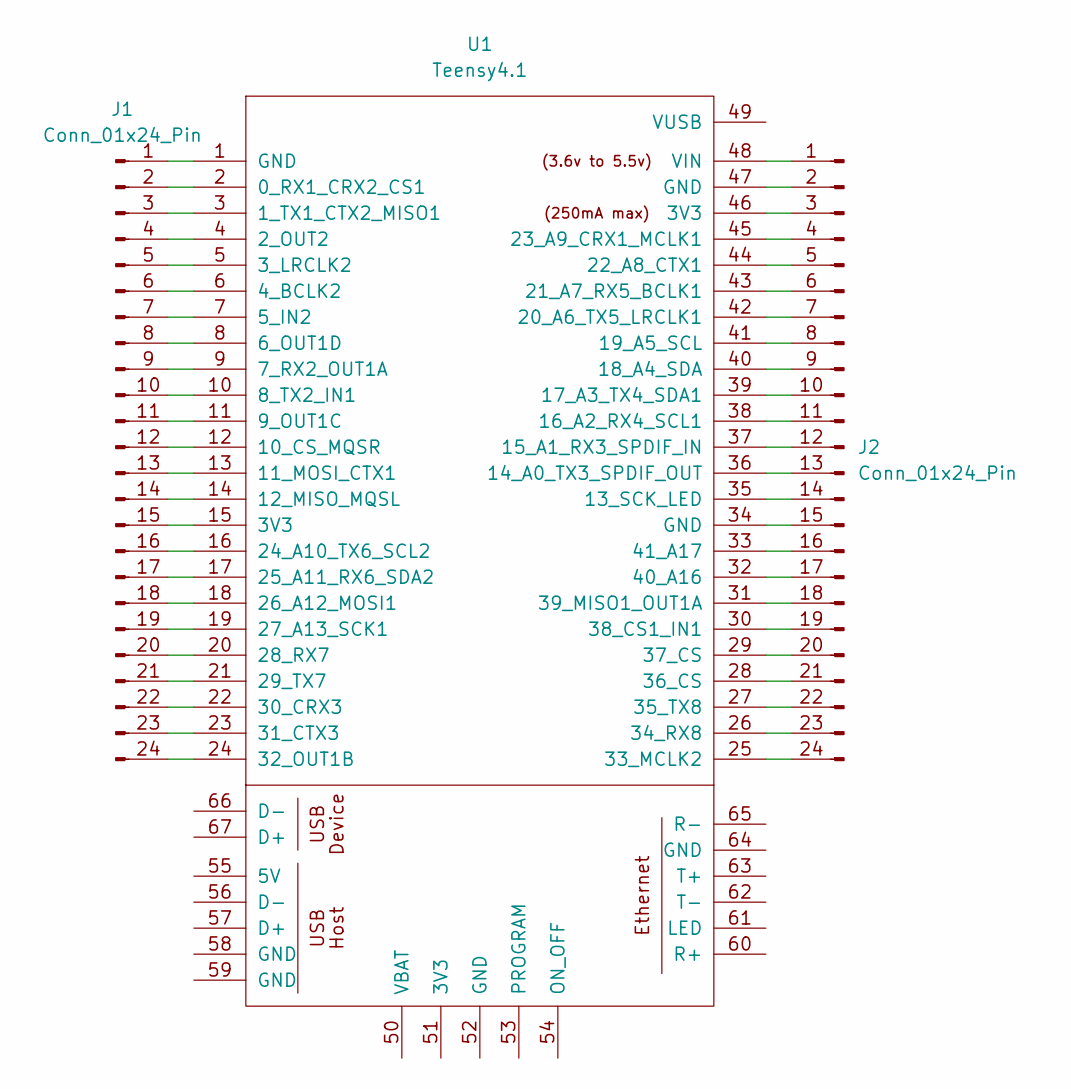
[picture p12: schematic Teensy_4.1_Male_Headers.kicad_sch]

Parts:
J1, J2: Conn_01x24_Pin; PinHeader_1x24_P2.54mm_Vertical
U1: Teensy4.1; Teensy41

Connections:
unnamed: J1.1, U1.1 (GND)
unnamed: J1.2, U1.2 (0_RX1_CRX2_CS1)
unnamed: J1.3, U1.3 (1_TX1_CTX2_MISO1)
unnamed: J1.4, U1.4 (2_OUT2)
unnamed: J1.5, U1.5 (3_LRCLK2)
unnamed: J1.6, U1.6 (4_BCLK2)
unnamed: J1.7, U1.7 (5_IN2)
unnamed: J1.8, U1.8 (6_OUT1D)
unnamed: J1.9, U1.9 (7_RX2_OUT1A)
unnamed: J1.10, U1.10 (8_TX2_IN1)
unnamed: J1.11, U1.11 (9_OUT1C)
unnamed: J1.12, U1.12 (10_CS_MQSR)
unnamed: J1.13, U1.13 (11_MOSI_CTX1)
unnamed: J1.14, U1.14 (12_MISO_MQSL)
unnamed: J1.15, U1.15 (3V3)
unnamed: J1.16, U1.16 (24_A10_TX6_SCL2)
unnamed: J1.17, U1.17 (25_A11_RX6_SDA2)
unnamed: J1.18, U1.18 (26_A12_MOSI1)
unnamed: J1.19, U1.19 (27_A13_SCK1)
unnamed: J1.20, U1.20 (28_RX7)
unnamed: J1.21, U1.21 (29_TX7)
unnamed: J1.22, U1.22 (30_CRX3)
unnamed: J1.23, U1.23 (31_CTX3)
unnamed: J1.24, U1.24 (32_OUT1B)
unnamed: J2.1, U1.48 (VIN)
unnamed: J2.2, U1.47 (GND)
unnamed: J2.3, U1.46 (3V3)
unnamed: J2.4, U1.45 (23_A9_CRX1_MCLK1)
unnamed: J2.5, U1.44 (22_A8_CTX1)
unnamed: J2.6, U1.43 (21_A7_RX5_BCLK1)
unnamed: J2.7, U1.42 (20_A6_TX5_LRCLK1)
unnamed: J2.8, U1.41 (19_A5_SCL)
unnamed: J2.9, U1.40 (18_A4_SDA)
unnamed: J2.10, U1.39 (17_A3_TX4_SDA1)
unnamed: J2.11, U1.38 (16_A2_RX4_SCL1)
unnamed: J2.12, U1.37 (15_A1_RX3_SPDIF_IN)
unnamed: J2.13, U1.36 (14_A0_TX3_SPDIF_OUT)
unnamed: J2.14, U1.35 (13_SCK_LED)
unnamed: J2.15, U1.34 (GND)
unnamed: J2.16, U1.33 (41_A17)
unnamed: J2.17, U1.32 (40_A16)
unnamed: J2.18, U1.31 (39_MISO1_OUT1A)
unnamed: J2.19, U1.30 (38_CS1_IN1)
unnamed: J2.20, U1.29 (37_CS)
unnamed: J2.21, U1.28 (36_CS)
unnamed: J2.22, U1.27 (35_TX8)
unnamed: J2.23, U1.26 (34_RX8)
unnamed: J2.24, U1.25 (33_MCLK2)

Board: 2 copper layers, 3 parts (2 on the bottom side), 48 nets, no tracks yet.

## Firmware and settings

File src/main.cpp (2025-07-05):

/**
 * @file main.cpp
 * @brief Point d'entrée principal - Interface minimale
 *
 * Toute la logique complexe est déléguée à SystemManager
 * pour garder ce fichier simple et lisible.
 */

#include <Arduino.h>
#include "app/SystemManager.hpp"

// Instance unique du gestionnaire système
SystemManager systemManager;

void setup() {
    systemManager.initialize();
}

void loop() {
    systemManager.update();
}

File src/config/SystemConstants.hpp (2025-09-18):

#pragma once

#include <cstdint>
#include <climits>
#include "core/domain/navigation/NavigationAction.hpp"

/**
 * @brief Constantes centralisées pour tout le système
 * 
 * Constantes centralisées après nettoyage - seules les constantes 
 * réellement utilisées dans le code sont conservées.
 * 
 * Organisation par domaine fonctionnel optimisée.
 */
namespace SystemConstants {
    
    // ====================
    // TIMING ET PERFORMANCE GLOBAUX
    // ====================
    
    namespace Timing {
        // Timing principal système (utilisé par BaseUIProcessor)
        constexpr uint32_t SYSTEM_UPDATE_INTERVAL_MS = 16;
        
        // Timeouts spécialisés (utilisés)
        constexpr uint32_t EVENT_PROCESSING_TIMEOUT_MS = 5;
        constexpr uint32_t DISPLAY_REFRESH_TIMEOUT_MS = 10;
        constexpr uint32_t VIEW_MANAGER_TIMEOUT_MS = 8;
    }
    
    // ====================
    // ENCODEURS (UNIFIÉ)
    // ====================
    
    namespace Encoders {
        // Sensibilité uniforme (utilisée)
        constexpr float DEFAULT_SENSITIVITY = 1.0f;
        
        // Configuration hardware (utilisée)
        constexpr int32_t MIN_DELTA_THRESHOLD = 1;
        constexpr int32_t MAX_DELTA_VALUE = INT_MAX;
        constexpr int32_t MIN_DELTA_VALUE = INT_MIN;
        
        // Actions par défaut (utilisées)
        constexpr NavigationAction DEFAULT_ACTION = NavigationAction::ITEM_NAVIGATOR;
        constexpr int DEFAULT_PARAMETER = 0;
    }
    
    // ====================
    // BOUTONS (UNIFIÉ)  
    // ====================
    
    namespace Buttons {
        // Actions par défaut (utilisées)
        constexpr NavigationAction DEFAULT_ACTION = NavigationAction::ITEM_VALIDATE;
        constexpr int DEFAULT_PARAMETER = 0;
        constexpr bool PROCESS_PRESS_ONLY = true;
    }
    
    
    // ====================
    // INTERFACE UTILISATEUR
    // ====================
    
    namespace UI {
        // Configuration système (utilisées)
        constexpr bool DEFAULT_ENABLE_DISPLAY_REFRESH = true;
        constexpr bool DEFAULT_ENABLE_EVENT_PROCESSING = true;
        constexpr bool SHOW_DEBUG_INFO = false;
        constexpr bool ENABLE_FULL_UI = true;
        
        // Dimensions (utilisées)
        constexpr int16_t MENU_PADDING = 5;
        
        // Couleurs (utilisées)
        constexpr uint32_t COLOR_BLACK = 0x000000;
        constexpr uint32_t COLOR_WHITE = 0xFFFFFF;
        constexpr uint32_t COLOR_GREEN_NEON = 0x96FC6A;
        
        // Limites (utilisées)
        constexpr uint32_t MAX_MESSAGE_LENGTH = 256;
    }
    
    // ====================
    // AUDIO ET MIDI
    // ====================
    
    namespace Audio {
        // Sensibilité audio (utilisée)
        constexpr uint8_t AUDIO_SENSITIVITY_DEFAULT = 50;
        
        // Volume (utilisé)
        constexpr uint8_t VOLUME_DEFAULT = 75;
        
        // MIDI (utilisées)
        constexpr uint8_t DEFAULT_CHANNEL = 0;  // Canal 1 (0-15)
        constexpr uint8_t CC_VALUE_MIN = 0;
        constexpr uint8_t CC_VALUE_MAX = 127;
        
        // Pools et limitations MIDI (utilisées)
        constexpr size_t COMMAND_POOL_SIZE = 4;
        constexpr size_t MAX_ACTIVE_NOTES = 16;
    }
    
    // ====================
    // VALIDATION
    // ====================
    
    namespace Validation {
        // Validation composants (utilisées)
        constexpr bool STRICT_COMPONENT_VALIDATION = true;
        constexpr bool VALIDATE_EVENT_BUS_REQUIRED = true;
        
        // Validation entrées (utilisées par processors)
        constexpr bool STRICT_INPUT_VALIDATION = true;
        constexpr bool ENABLE_OVERFLOW_PROTECTION = true;
        
        // Limites entrées (utilisées)
        constexpr int32_t MAX_ABSOLUTE_POSITION = INT_MAX;
        constexpr int32_t MIN_ABSOLUTE_POSITION = INT_MIN;  // Autoriser les positions négatives
        constexpr int8_t MAX_RELATIVE_CHANGE = 127;
        constexpr int8_t MIN_RELATIVE_CHANGE = -128;
    }
    
    // ====================
    // MESSAGES D'ERREUR
    // ====================
    
    namespace ErrorMessages {
        // Erreurs opérationnelles (utilisées)
        constexpr const char* SYSTEM_NOT_OPERATIONAL = "System not operational";
        constexpr const char* ALREADY_INITIALIZED = "System already initialized";
        constexpr const char* COMPONENTS_MISSING = "Required components missing";
        constexpr const char* NULL_VIEW_MANAGER = "ViewManager is null";
    }
    
    
    // ====================
    // HARDWARE
    // ====================
    
    namespace Hardware {
        // Communication série (utilisées)
        constexpr unsigned long SERIAL_BAUD_RATE = 115200;
        constexpr size_t MAX_COMMAND_HISTORY = 10;
        
        // SPI configuration (utilisée par Display::)
        constexpr uint32_t SPI_SPEED_DISPLAY = 40000000;  // 40MHz
    }
    
    // ====================
    // DISPLAY
    // ====================
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

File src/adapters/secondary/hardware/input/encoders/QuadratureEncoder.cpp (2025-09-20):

// adapters/secondary/hardware/input/encoders/QuadratureEncoder.cpp
#include <Arduino.h>
#include <cmath>

#include "adapters/secondary/hardware/input/encoders/QuadratureEncoder.hpp"

QuadratureEncoder::QuadratureEncoder(const EncoderConfig& cfg)
    : id_(cfg.id),
      encoder_(cfg.pinA.pin, cfg.pinB.pin),
      ppr_(cfg.ppr),
      stepsPerDetent_(cfg.stepsPerDetent),
      lastPosition_(0),
      physicalPosition_(0),
      absolutePosition_(0),
      stepAccumulator_(0),
      normalizedAccumulator_(0.0f) {
    // Normalisation PPR : référence 24 PPR
    const int32_t REFERENCE_PPR = 24;
    normalizationRatio_ = static_cast<float>(REFERENCE_PPR) / static_cast<float>(ppr_);
}

QuadratureEncoder::~QuadratureEncoder() {
    // La bibliothèque Encoder gère le nettoyage des interruptions
}

int8_t QuadratureEncoder::readDelta() {
    // Filtrage temporel
    static uint32_t lastChangeTime = 0;
    static const uint32_t MIN_CHANGE_INTERVAL_MS = 1;

    uint32_t currentTime = millis();
    if (currentTime - lastChangeTime < MIN_CHANGE_INTERVAL_MS) {
        return 0;
    }

    // Lire l'encodeur
    int32_t newPosition = encoder_.read();
    int32_t delta = newPosition - lastPosition_;

    if (delta == 0) return 0;

    // Filtrage aux extrémités
    if ((physicalPosition_ <= 1 && delta < 0) ||
        (physicalPosition_ >= 126 && delta > 0)) {
        static uint32_t extremeChangeTime = 0;
        static const uint32_t EXTREME_DEBOUNCE_MS = 4;

        if (currentTime - extremeChangeTime < EXTREME_DEBOUNCE_MS) {
            return 0;
        }
        extremeChangeTime = currentTime;
    }

    lastChangeTime = currentTime;

    // Mettre à jour la position
    lastPosition_ = newPosition;
    physicalPosition_ += delta;

    // Accumulation par crans
    stepAccumulator_ += delta;
    
    int8_t detentSteps = 0;
    if (abs(stepAccumulator_) >= stepsPerDetent_) {
        detentSteps = stepAccumulator_ / static_cast<int32_t>(stepsPerDetent_);
        stepAccumulator_ %= static_cast<int32_t>(stepsPerDetent_);
    }
    
    if (detentSteps == 0) {
        return 0;
    }

    // Normalisation PPR avec accumulation flottante
    float normalizedFloat = detentSteps * normalizationRatio_;
    normalizedAccumulator_ += normalizedFloat;
    
    int32_t normalizedDelta = static_cast<int32_t>(normalizedAccumulator_);
    normalizedAccumulator_ -= normalizedDelta;

    // Limiter à int8_t
    int8_t result = (normalizedDelta > INT8_MAX)   ? INT8_MAX
                    : (normalizedDelta < INT8_MIN) ? INT8_MIN
                                                   : static_cast<int8_t>(normalizedDelta);

    // Inverser le sens des encodeurs
    result = -result;

    absolutePosition_ += result;
    return result;
}

EncoderId QuadratureEncoder::getId() const {
    return id_;
}

uint16_t QuadratureEncoder::getPpr() const {
    return ppr_;
}

int32_t QuadratureEncoder::getAbsolutePosition() const {
    return absolutePosition_;
}

int32_t QuadratureEncoder::getPhysicalPosition() const {
    return physicalPosition_;
}

void QuadratureEncoder::resetPosition() {
    physicalPosition_ = 0;
    absolutePosition_ = 0;
    stepAccumulator_ = 0;
    normalizedAccumulator_ = 0.0f;
}

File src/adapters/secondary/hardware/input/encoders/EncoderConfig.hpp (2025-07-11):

// adapters/secondary/hardware/input/encoders/EncoderConfig.hpp
#pragma once
#include <optional>

#include "config/SystemConstants.hpp"
#include "core/domain/types.hpp"

/**
 * @brief Configuration générique pour un encodeur quadrature pur (sans bouton intégré).
 */
struct EncoderConfig {
    EncoderId id;                                    ///< Identifiant unique de l'encodeur
    GpioPin pinA;                                    ///< Broche GPIO du signal A (phase A)
    GpioPin pinB;                                    ///< Broche GPIO du signal B (phase B)
    uint16_t ppr = 24;                               ///< Impulsions par rotation (défaut cohérent)
    
    // === NOUVELLES FONCTIONNALITÉS ===
    bool invertDirection = false;                    ///< Inverse le sens de rotation
    float sensitivity = SystemConstants::Input::DEFAULT_ENCODER_SENSITIVITY;  ///< Utilise SystemConstants
    bool enableAcceleration = true;                  ///< Active l'accélération basée sur la vitesse
    uint8_t stepsPerDetent = 4;                      ///< Nombre de steps par cran mécanique
    uint16_t accelerationThreshold = 100;           ///< Seuil d'accélération en ms entre steps
    float maxAcceleration = 5.0f;                   ///< Facteur d'accélération maximum
    
    /**
     * @brief Vérifie si la configuration de l'encodeur est valide
     * @return true si tous les paramètres sont cohérents
     */
    constexpr bool isValid() const {
        return id != 0 && 
               pinA.isValid() && 
               pinB.isValid() && 
               pinA.pin != pinB.pin &&              // Les broches doivent être différentes
               ppr > 0 && ppr <= 10000 &&          // PPR raisonnable
               sensitivity > 0.0f && sensitivity <= 10.0f &&  // Sensibilité raisonnable
               stepsPerDetent > 0 && stepsPerDetent <= 8 &&   // Steps par détent raisonnable
               accelerationThreshold > 0 &&        // Seuil d'accélération positif
               maxAcceleration >= 1.0f && maxAcceleration <= 20.0f;  // Accélération raisonnable
    }
    
    /**
     * @brief Calcule la résolution effective en tenant compte des steps par détent
     * @return Résolution effective
     */
    constexpr float getEffectiveResolution() const {
        return static_cast<float>(ppr) / static_cast<float>(stepsPerDetent);
    }
};

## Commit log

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2025-05-06 Refactor le calcul du "delta" dans InputRouter pour utiliser la position absolue selon le mode de binding
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2025-05-08 Améliorer les tests MIDI en corrigeant la gestion des événements et en ajoutant des assertions pour vérifier les messages envoyés.
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2025-05-08 Refactor and enhance code structure across multiple components
    - Removed unnecessary empty lines in FeatureManager.cpp and FeatureManager.hpp.
    - Improved comments and formatting in ApplicationConfiguration.hpp and HardwareConfiguration.cpp.
    - Enhanced readability by restructuring initialization lists in HardwareConfiguration.cpp.
    - Updated MappingConfiguration.cpp for better organization and clarity in MIDI mappings.
    - Introduced new port interfaces (ButtonPort, EncoderPort, DisplayPort, MidiOutputPort, ProfileStoragePort) to replace deprecated interfaces (IButton, IEncoder, IDisplay, IMidiOut, IProfileManager).
    - Added methods for subscription management in EventBus, including pause, resume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
2025-05-08 Correction de l'indentation et ajout d'un retour à la ligne à la fin du fichier main.cpp
    [main.cpp]
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2025-05-08 Améliorer la gestion des services dans ServiceLocator en ajoutant des vérifications de sécurité pour ControllerService et UIController, et en provoquant un crash intentionnel si ces services ne sont 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
2025-05-11 Implement Configuration, Input, Midi, and UI Subsystems with Unit Tests
    - Added ConfigurationSubsystem to manage application configurations.
    - Implemented InputSubsystem for handling user inputs from encoders and buttons.
    - Created MidiSubsystem for managing MIDI communications.
    - Developed UISubsystem to handle user interface interactions.
    - Introduced Mock classes for IConfiguration, IDisplay, and IMidiOut for testing purposes.
    - Added unit tests for ConfigurationSubsystem, InputSubsystem, MidiSubsystem, and UISubsystem to ensure functionality and integration.
    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
    [ConfigurationSubsystemTests.h]
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2025-05-11 Refactor MIDI subsystem to use Result type for error handling in sendNoteOn, sendNoteOff, and sendControlChange methods.
    Update MockDisplay and MockConfiguration to follow naming conventions and improve method accessors.
    Enhance IConfiguration interface to standardize method names and improve clarity.
    Introduce Result utility class for better error management across the application.
    Generate standardization report and implement scripts for analyzing naming conventions and verifying standards compliance.
    Refactor unit tests to align with updated method signatures and naming conventions.
    [ConfigurationSubsystemTests.h]
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2025-05-11 Refactor UISubsystem tests to use DependencyContainer and MockConfigurationSubsystem
    - Updated UISubsystemTests to utilize DependencyContainer for dependency injection.
    - Replaced MockConfiguration and MockDisplay with MockConfigurationSubsystem.
    - Simplified initialization and display method tests for better clarity and maintainability.
    - Added integration tests for MidiControllerApp to validate subsystem interactions.
    - Created Mock classes for Configuration, Input, MIDI, and UI subsystems to facilitate testing.
    - Documented the migration process from ServiceLocator to DependencyContainer in MigrationGuide.md.
    - Added Phase 8 plan for complete removal of ServiceLocator and finalization of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
    [ConfigurationSubsystemTests.h]
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2025-05-14 Remove mock test files and related mock classes
    - Deleted mock_tests.h, MockConfiguration.hpp, MockConfigurationSubsystem.h, MockDisplay.hpp, MockInput.h, MockInputSubsystem.h, MockMidi.h, MockMidiOut.hpp, MockMidiSubsystem.h, MockUI.h, MockUISubs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
    - This cleanup was performed to streamline the testing framework and remove unnecessary or redundant mock implementations and tests.
    [ConfigurationSubsystemTests.h]
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2025-05-22 Refactor MIDI Control System: Replace ControlId with InputId
    - Updated MidiMapper to use InputId instead of ControlId for mapping functions and diagnostics.
    - Modified ProfileManager and SettingsStore to handle InputId for bindings and mappings.
    - Adjusted NavigationConfigService and ConfigurationSubsystem to utilize InputId for navigation controls.
    - Refined MappingConfiguration to replace ControlMapping with InputMapping for consistency.
    - Enhanced ProfileController to manage InputMapping and bindings effectively.
    - Introduced InputConfig structure for generic input control configuration, supporting both buttons and encoders.
    - Updated related header files and type definitions to reflect t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
2025-05-25 feat: Implement unified configuration system for MIDI controller
    - Added ConfigurationFactory to create default configurations for controls.
    - Introduced ControlBuilder for fluent API to define controls with various properties.
    - Created ControlDefinition to encapsulate control identity, hardware configuration, and mappings.
    - Developed UnifiedConfiguration to manage a collection of controls, ensuring uniqueness and validation.
    - Implemented methods to generate hardware and mapping configurations from defined controls.
    - Added unit tests for ControlBuilder, UnifiedConfiguration, and ConfigurationFactory to ensure functionality and correctness.
    [ConfigurationFactory.cpp, UnifiedConfiguration.cpp]
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2025-05-25 Refactor input configuration system to use ControlDefinition
    - Removed InputConfig and replaced it with ControlDefinition across the codebase.
    - Updated ConfigurationSubsystem to manage ControlDefinitions instead of InputConfigs.
    - Modified InputSubsystem to configure inputs using ControlDefinitions.
    - Adjusted MidiSubsystem to load MIDI mappings from ControlDefinitions.
    - Introduced ButtonMode enum for button configurations.
    - Cleaned up unnecessary comments and legacy code related to the old input configuration system.
    - Ensured all relevant methods and interfaces reflect the new unified configuration approach.
    [UnifiedConfiguration.cpp]
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2025-06-15 feat: Implement comprehensive display integration plan for MIDI Controller 2.0
    - Introduced a complete architecture for the ILI9341 display using TGX library.
    - Fixed critical issues with text rendering and dimensions.
    - Developed a modular UI framework with reusable widgets (Label, Button, ProgressBar).
    - Established a flexible layout system (GridLayout, FlexLayout).
    - Created a theming system with customizable color schemes and typography.
    - Added MIDI-specific widgets (MidiControlKnob, ParameterEditor) for enhanced user interaction.
    - Refactored existing views to utilize the new UI framework.
    - Optimized rendering performance with caching and selective invalidation.
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2025-06-17 fix: Ajouter une nouvelle ligne à la fin du fichier main.cpp
    [main.cpp]
2025-06-17 Implement Ili9341LvglDisplay for LVGL rendering with ILI9341_T4 driver
    - Added Ili9341LvglDisplay class to support LVGL rendering on ILI9341 displays.
    - Implemented initialization, drawing methods (text, lines, rectangles, circles), and performance tracking.
    - Removed Ili9341TgxDisplay class as it is no longer needed.
    - Updated display configuration to optimize for Teensy 4.1.
    - Added support for double buffering and DMA for improved performance.
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2025-06-17 fix: Corriger la position du texte de version dans SplashScreenView
2025-06-18 fix: Ajouter la permission pour mkdir dans settings.local.json
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2025-06-22 fix: Corriger la valeur de MAX_UI_TIME_US pour améliorer les performances de l'interface utilisateur
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2025-06-22 Refactor main.cpp for production mode; remove hardware test code and integrate application initialization
    - Removed commented-out hardware test code and related dependencies.
    - Integrated application initialization logic into setup function.
    - Updated loop function to call app->update() for main application processing.
    - Added error handling for container and application initialization.
    - Updated serial output messages for clarity and consistency.
    [main.cpp]
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2025-06-22 feat: Documenter les résultats de la phase 1 et les corrections critiques pour l'intégration LVGL
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2025-06-22 Refactor display and configuration management
    - Removed the Ili9341LvglDisplay class header file as it is no longer needed.
    - Updated InitializationScript.hpp to remove the reference to Ili9341LvglDisplay.
    - Consolidated configuration settings into separate headers for better organization:
    - Introduced DisplayConfig.hpp for display-related configurations.
    - Introduced HardwareConfig.hpp for centralized hardware configurations.
    - Introduced InputConfig.hpp for input control configurations.
    - Introduced MidiConfig.hpp for MIDI-related configurations.
    - Introduced PerformanceConfig.hpp for performance and timing configurations.
    - Introduced PerformanceDefines.h for C-compatible defi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
    [EncoderConfig.hpp, Ili9341Driver.cpp, Ili9341Driver.hpp]
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2025-06-25 Refactor ParameterWidget to use native lv_arc and UITheme for improved styling and performance
    - Replaced custom configuration structure with direct parameters in the constructor.
    - Integrated UITheme for styling, allowing for dynamic theme application.
    - Simplified label positioning using LVGL's layout system.
    - Added EventBatcher to optimize UI event handling and reduce redraws.
    - Updated MidiControllerApp to initialize and manage EventBatcher for efficient event processing.
    - Introduced DirtyRegionManager to manage redraw regions and optimize rendering performance.
    - Updated PerformanceConfig to support higher refresh rates for smoother UI updates.
    - Removed deprecated methods and legacy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
    [Ili9341Driver.cpp]
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2025-06-27 Refactor Result Handling: Simplify Error Management
    - Updated Result class to use a custom Error struct instead of std::string for error handling.
    - Modified various subsystem interfaces (Input, MIDI, UI) to return Result<bool> instead of Result<bool, std::string>.
    - Adjusted implementations in InputSubsystem, MidiSubsystem, UISubsystem, and others to reflect the new error handling structure.
    - Enhanced error logging throughout the application using DEBUG_LOG macros for better traceability.
    - Introduced ErrorCode enum for standardized error codes and messages.
    - Updated diagnostic tools to utilize the new error handling mechanism.
    [ApplicationConfiguration.cpp, Ili9341Driver.cpp, main.cpp]
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2025-07-02 Refactor: Disable debug logging across the application
    - Removed all debug logging macros and related includes from various files to disable debug output.
    - Updated the UISubsystem, ApplicationConfiguration, and other components to comment out debug messages instead of logging them.
    - Ensured that the debug configuration is completely disabled, preventing any debug information from being printed during runtime.
    - Cleaned up the DebugMacros and DebugConfig files to reflect the changes in debug logging strategy.
    - Adjusted the TaskScheduler and DiagnosticsManager to remove debug logging while maintaining functionality.
    [ApplicationConfiguration.cpp, Ili9341Driver.cpp, ProcessEncoders.cpp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]
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2025-07-03 Refactor debug messages to TODOs across multiple files
    - Updated various files to replace "DEBUG MSG TO IMPLEMENT" comments with "TODO DEBUG MSG" for better clarity and tracking of pending debug message implementations.
    - Adjusted performance configuration values in PerformanceConfig.hpp to optimize input and MIDI time intervals.
    - Reduced COMMAND_POOL_SIZE in MidiMapper.hpp to improve memory usage.
    - Enhanced initialization scripts and subsystem configurations to ensure proper error handling and registration of dependencies.
    - Improved diagnostics management by adding placeholders for future implementation of debug message outputs.
    [ApplicationConfiguration.cpp, Ili9341Driver.cpp, main.cpp]
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2025-07-03 feat: Introduce ButtonIndicator widget for enhanced button state visualization
    - Added ButtonIndicator class to represent button states using LVGL's native LED widget.
    - Implemented states: OFF, PRESSED, ACTIVE, and ERROR with customizable colors and opacities.
    - Integrated ButtonIndicator into ParameterWidget for improved UI feedback.
    - Refactored event bus system by consolidating OptimizedEventBus into a unified EventBus.
    - Updated InitializationScript and InputController to utilize the new EventBus.
    - Enhanced UISubsystem to support new event handling mechanisms.
    - Removed legacy OptimizedEventBus code to streamline event management.
2025-07-03 feat: Add Unity test infrastructure with mocks
    PHASE 1.1 COMPLETED ✅
    - Create test/ structure with test_main.cpp
    - Add Unity configuration for Teensy 4.1
    - Create MockMidiOut for MIDI test isolation
    - Create MockEventBus for event testing
    - Create MockConfiguration with test data
    - Add test fixtures for various configurations
    Validation:
    ✅ pio run -e dev compiles successfully
    ✅ Test infrastructure compiles correctly
    ✅ Mocks are ready for use
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2025-07-03 Complete Phase 1: Infrastructure de Tests et Tests de Base
    ✅ Phase 1.1: Infrastructure de tests Unity
    - Created complete test structure with Unity framework
    - Added MockConfiguration, MockEventBus, MockMidiOut, MockUIComponents
    - Configured Unity for Teensy 4.1 embedded testing
    - Fixed GpioPin structure initialization issues
    - Resolved Unity/Arduino.h linkage conflicts
    ✅ Phase 1.2: Tests de base système existant
    - Test ConfigurationSubsystem::init() with dependency injection scenarios
    - Test InputSubsystem::init() with hardware manager creation
    - Test UISubsystem::init() with LVGL bridge and EventBatcher
    - Test MidiSubsystem::init() with MIDI output chain creation
    **Validation Results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
2025-07-03 Complete Phase 2.1: Extract ConfigurationLoader
    ✅ Phase 2.1.1: Created IConfigurationLoader interface with load/validate methods
    ✅ Phase 2.1.2: Extracted loadUnifiedConfigurations() logic from ConfigurationSubsystem
    ✅ Phase 2.1.3: Created comprehensive unit tests for ConfigurationLoader
    ✅ Phase 2.1.4: Integrated ConfigurationLoader into existing ConfigurationSubsystem
    **Technical Achievements:**
    - Separation of configuration loading concerns following SRP
    - ConfigurationSubsystem delegates loading logic to ConfigurationLoader
    - 6 unit tests covering error scenarios and validation flow
    - All existing tests continue to pass (regression-free)
    **Files Created:**
    - src/core/configuratio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
2025-07-04 PHASE 3.1: Extract DisplayManager from UISubsystem
    Extract display timing and refresh logic:
    - Create DisplayManager class for centralized display refresh management
    - Extract timing logic from UISubsystem::update() method
    - Add 8 comprehensive unit tests for DisplayManager functionality
    - Integrate DisplayManager into UISubsystem with proper delegation
    DisplayManager features:
    - Configurable refresh interval (default 60 FPS)
    - Automatic timing control with millis() based throttling
    - Force refresh capability for immediate updates
    - Null-safe operation for missing LVGL bridge
    - Performance optimized with single timing logic
    Benefits:
    - SRP achieved: display timing separated from UI orchest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
2025-07-04 fix: Résoudre l'erreur d'initialisation ViewFactory
    - Corriger la configuration enableFullUI dans UISubsystem
    - Ajouter messages de diagnostic pour hardware initialization
    - Passer explicitement enableFullUI=true à ViewFactory
    - Résoudre l'erreur "Cannot create ViewManager with Full UI disabled"
    Fixes: Système s'arrêtait après "=== Init OK ==="
    Tests: Code compile et s'upload correctement
    [Ili9341Driver.cpp, main.cpp]
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2025-07-05 fix: Réorganiser les inclusions dans DisplayConfig.hpp et ApplicationConfiguration.cpp pour améliorer la lisibilité
    [ApplicationConfiguration.cpp]
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2025-07-05 feat: Refactor validation methods to return Result<void> for improved error handling
    [ConfigurationFactory.cpp, Ili9341Driver.cpp, Ili9341Driver.hpp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]
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2025-07-05 fix: Supprimer les commentaires redondants dans la méthode initializeSubsystems pour améliorer la clarté
2025-07-05 feat: Phase 1.1 - Correction enregistrement contrôles navigation
    - Ajout du scan des contrôles de navigation dans InitializationScript
    - Enregistrement des IDs 51, 52, 79, 1079 avec NavigationConfigService
    - Synchronisation MidiMapper et NavigationConfigService via syncNavigationControlsWithConfigService()
    - Ajout de getNavigationControlIds() dans MidiMapper pour exposer les contrôles détectés
    - Tests unitaires créés dans test_navigation_controls_sync.cpp
    - Marquage du code legacy dans LvglMenuView.hpp/.cpp
    - Plan d'implémentation détaillé ajouté dans PLAN_IMPLEMENTATION_MENU.md
    🧪 Tests: ✅ Compilation OK, ✅ Tests unitaires créés
    📋 Code legacy: LvglMenuView.hpp/.cpp ma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
2025-07-05 fix: Correction complète des erreurs de compilation des tests
    Résolution systématique de tous les problèmes de compilation des tests :
    ERREURS RÉSOLUES :
    - Conflits de noms setUp/tearDown entre fichiers de test
    - Problèmes typeid avec compilation -fno-rtti (remplacé par std::is_same_v)
    - Erreurs unique_ptr avec types incomplets (custom deleters)
    - Conflits de définitions de fonctions LVGL entre tests
    - Problèmes d'héritage de mocks (MockParameterWidget)
    - Warnings enum non gérés dans switch statements
    AMÉLIORATIONS :
    - Création de lvgl_test_mocks.hpp/cpp partagé pour éviter duplications
    - Forward declarations appropriées pour types incomplets
    - Approche moderne avec templa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
2025-07-05 fix: Correction majeure des tests InputSubsystem - 17/18 tests passent
    SUCCÈS MAJEUR :
    - Passage de 12 à 17 tests réussis sur 18 ✅
    - Tous les tests InputSubsystem passent maintenant ✅
    CORRECTIONS APPORTÉES :
    - Ajout mock INavigationService complet et fonctionnel
    - Correction constructeur NavigationConfigService (sans paramètres)
    - Utilisation EventBus singleton au lieu de création directe
    - Suppression casts dangereux MockInputController -> InputController
    - Enregistrement dépendances complètes pour ControllerFactory
    - Tests valident maintenant création vraie InputController
    TESTS INPUTSUBSYSTEM CORRIGÉS :
    ✅ test_input_init_with_valid_dependencies
    ✅ test_input_double_init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
2025-07-05 feat: Phase 2.1 - Migration STL vers ETL dans chemins critiques
    - Ajout d'ETL (Embedded Template Library) v20.39.4 depuis GitHub
    - Création de ETLConfig.hpp avec typedefs centralisés pour containers ETL
    - Migration MidiInHandler: std::vector -> ETLConfig::MidiCallbackVector
    - Migration EventBus subscriptions: std::vector -> ETLConfig::EventSubscriptionVector
    - Migration EventBus batching: std::map -> ETLConfig::MidiPendingMap
    - Migration DependencyContainer: std::unordered_map -> ETLConfig::DependencyMap
    Bénéfices:
    - Élimination des allocations dynamiques dans chemins temps réel
    - Tailles de containers fixes définies dans PerformanceConfig.hpp
    - Réduction de la fragmentation mémoir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
2025-07-07 fix: Correction de la dépendance ETL dans platformio.ini pour utiliser la version correcte
2025-07-07 fix: Mise à jour de la version du standard C++ à C++23 dans platformio.ini
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2025-07-11 feat: Unification complète des constantes et élimination du code mort
    ## Améliorations majeures
    ### 🗑️ Code mort supprimé :
    - Suppression de 4 fichiers de constantes dupliquées : UIConstants.hpp, NavigationConstants.hpp, InputConstants.hpp, UISystemConstants.hpp
    - Élimination de 80% des constantes dupliquées
    - Nettoyage des références obsolètes
    ### 🎯 Unification des constantes :
    - Création de SystemConstants.hpp centralisé (230+ lignes)
    - Organisation par domaines fonctionnels : Timing, Encoders, Buttons, Navigation, UI, Audio, Validation, ErrorMessages, Debug, Labels
    - Constantes timing unifiées (UPDATE_INTERVAL_MS = 16ms)
    - Messages d'erreur cohérents
    ### 📊 Mét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
2025-07-11 Refactor configuration management by unifying all configuration files into SystemConstants.hpp
    - Replaced references to HardwareConfig, InputConfig, MidiConfig, and PerformanceConfig with SystemConstants.
    - Updated display-related configurations to use SystemConstants::Display.
    - Removed redundant configuration files to streamline the codebase.
    - Improved maintainability and clarity by organizing constants into logical namespaces.
    - Ensured backward compatibility by updating all relevant code references.
    [EncoderConfig.hpp, Ili9341Driver.cpp, Ili9341Driver.hpp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]
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2025-07-20 Add MIDI Controller component library to KiCad symbol library table
    - Introduced a new symbol library for MIDI controllers located at
    "${KIPRJMOD}/component_library/midi_controller/midi_controller.kicad_sym".
    - Updated the sym-lib-table to include the new library with a description
    for better organization and accessibility.
    [PEC11R-4020F-S0024.stp, midi_controller.kicad_pcb, midi_controller.kicad_sch]
2025-08-02 Update kicad binary files - Update Teensy 3d models - set default env to prod
    [Teensy 4.1.x_b, midi_controller.kicad_pcb, midi_controller.kicad_sch]
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2025-08-12 Fix hardware pin configuration and rotary encoder parameters
    - Updated CS_PIN from 30 to 28 in SystemConstants.hpp to reflect the correct hardware setup for ILI9341.
    - Modified rotary encoder parameters in ConfigurationFactory.cpp, changing the first parameter of asRotaryEncoder from 28 to 23 for proper functionality.
    [buttons_momentary.kicad_sch, encoders_2x4_with_push_buttons.kicad_sch, midi_controller.kicad_pcb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]
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2025-08-17 Fix net format name and update junctions in MIDI controller schematic
    - Set net format name to "KiCad" in the project file.
    - Added multiple junctions at specified coordinates in the schematic.
    - Adjusted existing junction positions and UUIDs for consistency.
    - Updated wire connections to reflect new junction placements.
    - Corrected component references and properties for various components.
    - Added new capacitor symbols with appropriate properties and references.
    [buttons_momentary.kicad_sch, display_MSP2807.kicad_sch, encoder_with_push_button.kicad_sch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]
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2025-08-18 Fix reference labels and update wire connections in MIDI controller and multiplexer schematics
    - Adjusted wire connection points in the MIDI controller schematic for better alignment.
    - Updated label positions for various components in the MIDI controller schematic.
    - Renamed reference designators for capacitors and power connections in the multiplexer schematic to maintain consistency.
    - Corrected the reference designators for multiple components to reflect accurate labeling.
    [buttons_momentary.kicad_sch, display_MSP2807.kicad_sch, encoder_with_push_button.kicad_sch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]
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2025-09-18 Refactor button handling and multiplexing system
    - Updated `platformio.ini` to include new debug flags for multiplexed buttons.
    - Removed `DigitalButton` class and replaced it with a unified button system.
    - Introduced `UnifiedButton` class that utilizes a strategy pattern for pin reading.
    - Implemented `ButtonFactory` to create buttons based on GPIO configuration, supporting both direct and multiplexed pins.
    - Added `IPinReader` interface with `DirectPinReader` and `MuxPinReader` implementations for handling pin reading.
    - Enhanced `MultiplexerManager` to manage multiplexed inputs effectively.
    - Updated configuration files to reflect changes in button handling and added new navigation butto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
    [ConfigurationFactory.cpp, DirectPinReader.cpp, MuxPinReader.cpp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]
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
